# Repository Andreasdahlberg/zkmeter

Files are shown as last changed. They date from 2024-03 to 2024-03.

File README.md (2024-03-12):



# ZK-meter

ZK-meter is a Zigbee HAN-module for Kamstrup Omnipower electricity meters.

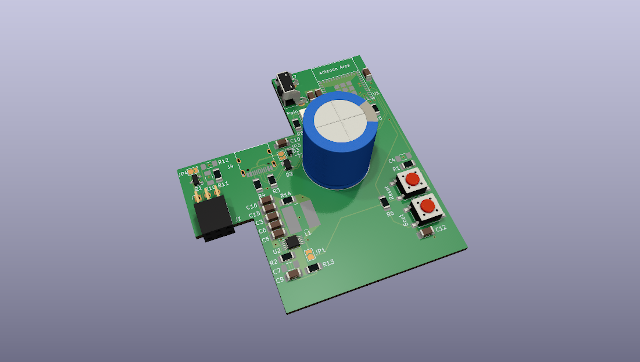
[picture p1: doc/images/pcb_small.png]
ZK-Meter PCB WIP PCB


## Features

 * No external power supply needed
 * Fits inside Kamstrump HAN-module casing
 * Supports Zigbee 3.0

## Getting started

### Assembly

1. Open the HAN-Module casing:
    * Use a small screwdriver to release the two clips located on both sides of the HAN-module casing.
    * Gently pull the top cover off to expose the interior.

1. Replace the PCB:
    * Remove the original PCB from its position.
    * Insert the ZK-meter PCB in the same location. Ensure that it fits precisely as the original PCB did.

1. Secure the Top Cover:
    * Place the top cover back onto the HAN-module casing.
    * Press down to secure the top cover in place.

### Installation

1. Insert the HAN-Module:
    * Identify the HAN-port on your meter. It is typically positioned above the display.
    * Carefully insert the HAN-module into the HAN-port.
    * Wait for the LED next to the pairing button to illuminate.

1. Activate Pairing Mode:
    * Press and hold the pairing button on the HAN-module.
    * Keep holding until the LED flashes, indicating that the device is now in pairing mode.

## Troubleshooting

## Development

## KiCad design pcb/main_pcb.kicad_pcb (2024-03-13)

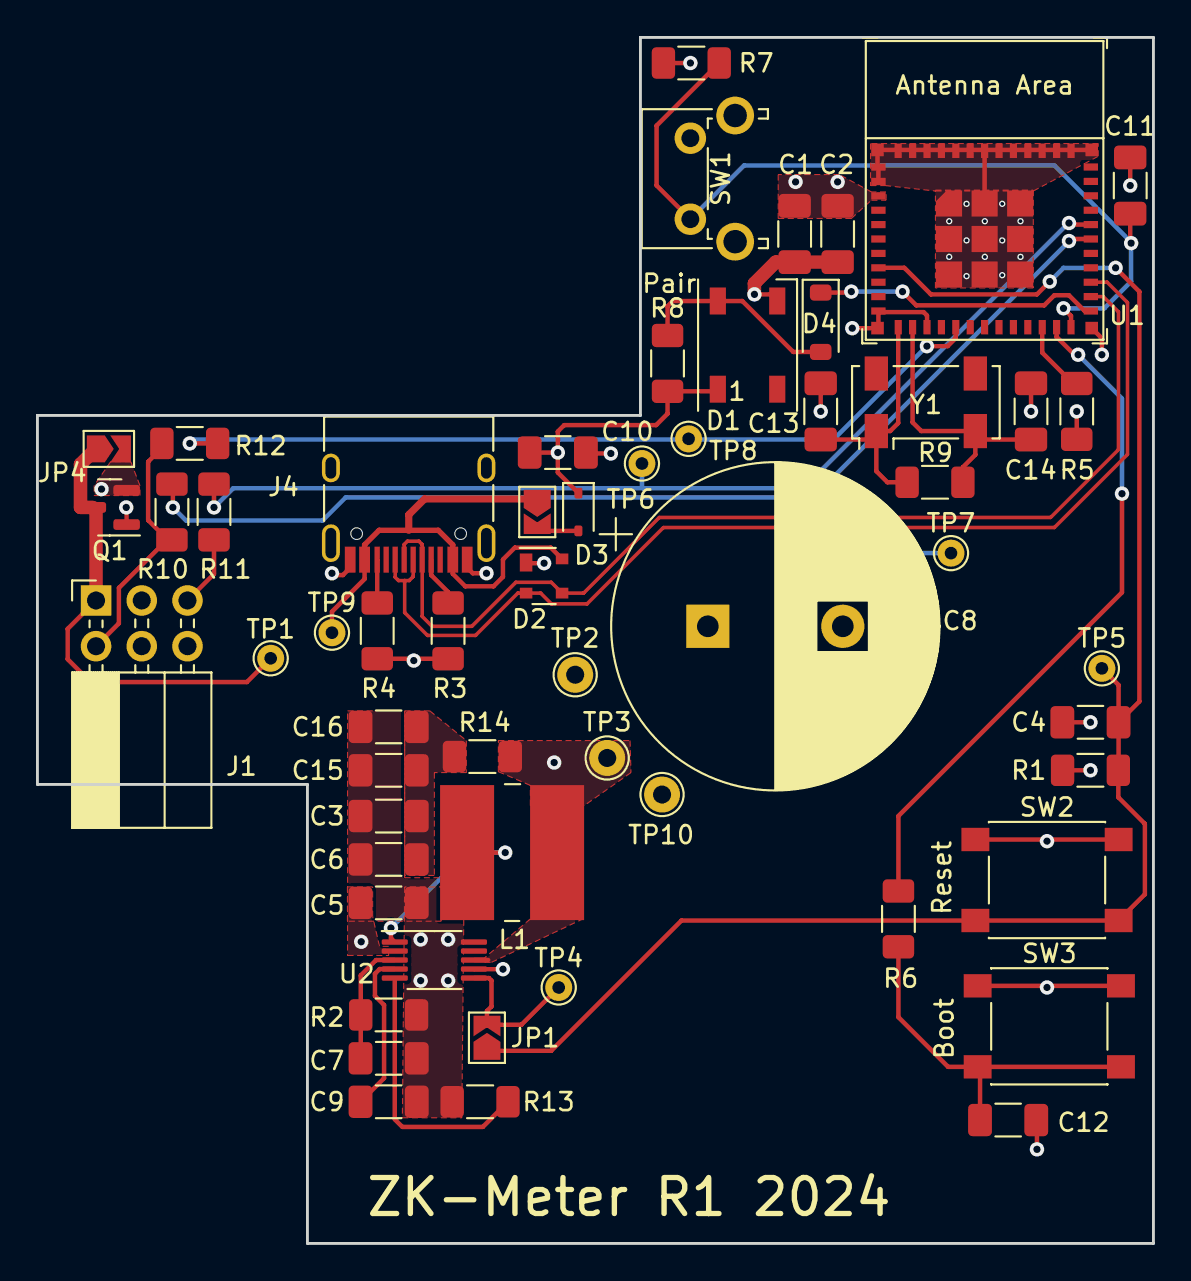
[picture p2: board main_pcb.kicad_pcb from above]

Board: 4 copper layers, 62.0 x 67.0 mm, 57 parts (0 on the bottom side), 30 nets.

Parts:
C1, C12: 0.1uF; C_1206_3216Metric_Pad1.33x1.80mm_HandSolder
C2, C10: 10uF; C_1206_3216Metric_Pad1.33x1.80mm_HandSolder
C3, C6, C15, C16: 4.7uF; C_1206_3216Metric_Pad1.33x1.80mm_HandSolder
C4, C5, C7, C11: 1uF; C_1206_3216Metric_Pad1.33x1.80mm_HandSolder
C8: 1F; CP_Radial_D18.0mm_P7.50mm
C9: 82nF; C_1206_3216Metric_Pad1.33x1.80mm_HandSolder
C13, C14: 12pF; C_1206_3216Metric_Pad1.33x1.80mm_HandSolder
D1: WS2812B; LED_WS2812B_PLCC4_5.0x5.0mm_P3.2mm
D2: SP0503BAHT; SOT-143
D3: 1N5819WS; D_SOD-323
D4: 1N4148W; D_SOD-123
J1: Conn_01x06_Socket; PinSocket_2x03_P2.54mm_Horizontal
J4: USB_C_Receptacle_USB2.0; USB_C_Receptacle_HRO_TYPE-C-31-M-12
JP1, JP3: SolderJumper_2_Bridged; SolderJumper-2_P1.3mm_Open_TrianglePad1.0x1.5mm
JP4: SolderJumper_2_Open; SolderJumper-2_P1.3mm_Open_TrianglePad1.0x1.5mm
L1: 56uH; L_Wuerth_WE-PD2-Typ-L
Q1: Si2323DS; SOT-23
R1, R5, R6, R7, R8: 10k; R_1206_3216Metric_Pad1.30x1.75mm_HandSolder
R2: 110k; R_1206_3216Metric_Pad1.30x1.75mm_HandSolder
R3, R4: 5k1; R_1206_3216Metric_Pad1.30x1.75mm_HandSolder
R9: 5.1M; R_1206_3216Metric_Pad1.30x1.75mm_HandSolder
R10, R11, R12: 0; R_1206_3216Metric_Pad1.30x1.75mm_HandSolder
R13: 59k; R_1206_3216Metric_Pad1.30x1.75mm_HandSolder
R14: 1.1; R_1206_3216Metric_Pad1.30x1.75mm_HandSolder
SW1: Pair; SW_Tactile_SPST_Angled_PTS645Vx31-2LFS
SW2: Reset; SW_SPST_PTS645
SW3: Boot; SW_SPST_PTS645
TP1: VIN; TestPoint_THTPad_D1.5mm_Drill0.7mm
TP2: VDD; TestPoint_THTPad_D2.0mm_Drill1.0mm
TP3: +3.3V; TestPoint_THTPad_D2.0mm_Drill1.0mm
TP4: PGOOD; TestPoint_THTPad_D1.5mm_Drill0.7mm
TP5: EN; TestPoint_THTPad_D1.5mm_Drill0.7mm
TP6: RXD; TestPoint_THTPad_D1.5mm_Drill0.7mm
TP7: TXD; TestPoint_THTPad_D1.5mm_Drill0.7mm
TP8: DATA_IN; TestPoint_THTPad_D1.5mm_Drill0.7mm
TP9: VBUS; TestPoint_THTPad_D1.5mm_Drill0.7mm
TP10: GND; TestPoint_THTPad_D2.0mm_Drill1.0mm
U1: ESP32-H2-MINI-1
U2: LM5165Y; VSSOP-10_3x3mm_P0.5mm
Y1: 32.768KHz; Crystal_SMD_Abracon_ABS25-4Pin_8.0x3.8mm

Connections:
+3.3V: C1.1, C2.1, C8.1, L1.2, R1.1, R5.2, R14.1, SW1.2, TP3.1, U1.3 (3V3), U2.8 (VOUT)
/D+: D2.2 (K), J4.A6 (D+), J4.B6 (D+), U1.27 (GPIO27/FSPICS5/USB_D+)
/D-: D2.3 (K), J4.A7 (D-), J4.B7 (D-), U1.26 (GPIO26/FSPICS4/USB_D-)
/DATA_IN: R12.2, TP8.1, U1.16 (GPIO12)
/EN: C4.1, JP1.1 (A), R1.2, SW2.2, TP5.1, U1.8 (EN)
/LED: D4.1 (K), U1.25 (GPIO25/FSPICS3)
/PAIR: C11.1, R7.2, SW1.1, U1.24 (GPIO22)
/RXD: R11.2, TP6.1, U1.31 (GPIO24/FSPICS2/U0TXD)
/TXD: R10.2, TP7.1, U1.30 (GPIO23/FSPICS1/U0RXD)
GND: C1.2, C2.2, C3.2, C4.2, C5.2, C6.2, C7.2, C8.2, C9.2, C10.2, C11.2, C12.2, C13.2, C14.2, C15.2, C16.2, D1.3 (VSS), D2.1 (A), J1.6, J4.A1 (GND), J4.A12 (GND), J4.B1 (GND), J4.B12 (GND), Q1.1 (G), R2.2, R3.2, R4.2, R7.1, R13.2, SW2.1, SW3.1, TP10.1, U1.1 (GND), U1.2 (GND), U1.11 (GND), U1.14 (GND), U1.36 (GND), U1.37 (GND), U1.38 (GND), U1.39 (GND), U1.40 (GND), U1.41 (GND), U1.42 (GND), U1.43 (GND), U1.44 (GND), U1.45 (GND), U1.46 (GND), U1.47 (GND), U1.48 (GND), U1.49 (GND), U1.50 (GND), U1.51 (GND), U1.52 (GND), U1.53 (GND), U2.10 (GND)
unnamed: C12.1, R6.2, SW3.2
unnamed: C3.1, C6.1, C15.1, C16.1, R14.2
unnamed: D1.4 (DIN), D4.2 (A), R8.1
unnamed: D3.2 (A), JP3.2 (B)
unnamed: J1.1, JP4.1 (A), Q1.3 (D), TP1.1
unnamed: J1.2, R10.1, R12.1
unnamed: J1.5, R11.1
unnamed: J4.A5 (CC1), R3.1
unnamed: J4.B5 (CC2), R4.1
unnamed: JP1.2 (B), TP4.1, U2.6 (PGOOD)
unnamed: R5.1, U1.22 (GPIO8)
unnamed: R6.1, U1.23 (GPIO9)
unnamed: C13.1, R9.1, U1.12 (GPIO13/XTAL_32K_P), Y1.1
unnamed: C14.1, R9.2, U1.13 (GPIO14/XTAL_32K_N), Y1.2
unnamed: C7.1, R2.1, U2.3 (ILIM)
unnamed: R13.1, U2.5 (RT)
unnamed: C9.1, U2.4 (SS)
unnamed: L1.1, U2.1 (SW)
VBUS: D2.4 (K), J4.A4 (VBUS), J4.A9 (VBUS), J4.B4 (VBUS), J4.B9 (VBUS), JP3.1 (A), TP9.1
VDD: C5.1, C10.1, D1.1 (VDD), D3.1 (K), JP4.2 (B), Q1.2 (S), R8.2, TP2.1, U2.2 (VIN), U2.7 (EN)

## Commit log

2024-02-12 Update kibot.yml
    Use container with Kicad 7.
2024-02-15 Add JTAG header
    [main_pcb.kicad_pcb, main_pcb.kicad_sch]
2024-02-15 Add FTDI header
    [main_pcb.kicad_pcb, main_pcb.kicad_sch]
2024-02-15 Add optional soft start capacitor to power circuit
    [main_pcb.kicad_pcb, main_pcb.kicad_sch]
2024-02-15 Add USB-C receptacle
    [main_pcb.kicad_pcb, main_pcb.kicad_sch]
2024-02-15 Add boot selection circuit
    [main_pcb.kicad_pcb, main_pcb.kicad_sch]
2024-02-15 Add ESD protection to USB data lines
    [main_pcb.kicad_pcb, main_pcb.kicad_sch]
2024-02-16 Improve USB circuit
    Add reverse voltage protection and VBUS capacitor.
    [main_pcb.kicad_pcb, main_pcb.kicad_sch]
2024-02-19 Add reverse current protection to HAN-interface
    [main_pcb.kicad_pcb, main_pcb.kicad_sch]
2024-02-19 Replace FTDI power pin jumper with solder bridge
    [main_pcb.kicad_pcb, main_pcb.kicad_sch]
2024-02-19 Add pair button circuit
    [main_pcb.kicad_pcb, main_pcb.kicad_sch]
2024-02-19 Add capacitor to boot switch
    [main_pcb.kicad_sch]
2024-02-19 Add status LED circuit
    [main_pcb.kicad_pcb, main_pcb.kicad_sch]
2024-02-19 Add RTC crystal circuit
    [main_pcb.kicad_pcb, main_pcb.kicad_sch]
2024-02-19 Add GND connection to ESP32-H2
    [main_pcb.kicad_sch]
2024-02-19 Remove FTDI connector
    [main_pcb.kicad_pcb, main_pcb.kicad_sch]
2024-02-19 Add HAN interface connections to ESP32
    [main_pcb.kicad_pcb, main_pcb.kicad_sch]
2024-02-20 Add keep out areas to PCB
    [main_pcb.kicad_pcb]
2024-02-20 Only render one frame using Blender
2024-02-20 Remove JTAG connector
    Planning on using the built in JTAG via USB.
    [main_pcb.kicad_pcb, main_pcb.kicad_sch]
2024-02-20 Change to 4 layer PCB
    [main_pcb.kicad_pcb]
2024-02-21 Remove redundant capacitor from reset circuit
    [main_pcb.kicad_sch]
2024-02-21 Label switches properly
    [main_pcb.kicad_sch]
2024-02-21 First rough PCB layout
    [main_pcb.kicad_pcb]
2024-02-27 Update power supply circuit
    Use values recomended by TI webench power designer.
    [main_pcb.kicad_sch]
2024-02-28 Improve PCB layout
    [main_pcb.kicad_pcb, main_pcb.kicad_sch]
2024-03-07 Update PCB layout
    [main_pcb.kicad_pcb]
2024-03-12 Fix DRC errors
    [main_pcb.kicad_pcb]
2024-03-12 Adjust designator positions
    [main_pcb.kicad_pcb]
2024-03-13 Add test points
    [main_pcb.kicad_pcb, main_pcb.kicad_sch]
2024-03-13 Increase copper fill free area around the antenna
    [main_pcb.kicad_pcb]
2024-03-13 Improve connection between 3.3 vreg and 3.3 power plane
    [main_pcb.kicad_pcb]
2024-03-13 Fix incorrect thermal reliefs
    [main_pcb.kicad_pcb]
2024-03-13 Add GND test point
    [main_pcb.kicad_pcb, main_pcb.kicad_sch]
